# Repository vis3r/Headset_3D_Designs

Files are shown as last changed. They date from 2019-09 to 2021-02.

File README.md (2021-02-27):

# Headset_3D_Designs
## The Vis3r Open Source 3D printable headset - STL and STEP source files. 

At current prices, you ought to be able to print this and get all the electronic components that you need for less than €75, although this changes on a daily basis. The components are often on special offer on AliExpress & Banggood, so it really pays to shop around.

The Headset was designed by Justin, the CAD files for the MIPI and HDMI boards were kindly provided by **Bio Toa7**

## The headset has finished Beta Testing
Here we are in early 2021, just coming out of virus lockdown - which unfortunately stopped our project development for what seemed like forever. However, we have still managed to finish Beta testing the headset and have finally released it out into the wild. The entire design was done from scratch in Autodesk Fusion 360 using one of their free licenses. The original F360 files can be given to anyone who needs them, so just ask.

If you find a problem, please post an issue and we will do our best to fix it ASAP. 

## Basic printing instructions
The headset is made of three main components, some of which have multiple parts. The entire design is purpose made to print with no supports. You shouldn't need to use a Skirt either, although a small Brim is probably a good idea.

### The Visual_Guide, Screen_Holder and Lens_Slides
As these incorporate screw threads and sliding components, you need to print with these settings:

* NO SUPPORTS
* 95% Infill
* 2 perimiter walls
* 4 Top Layers, 4 bottom layers

There are actually almost no "thick" areas, so they are very lightweight. A layer height of 0.2 or 0.24 is fine for these.

### The Main Body
As long as you print this with 2 perimiter walls, you can drop the infill down to 5% - & you will still find that they are rock solid. Again, they are designed specifically to print with NO SUPPORTS. Because they are almost completely hidden by the Outer_Shell, you can easily print these with a layer height of  0.24 or 0.28, and I would definitely not advise any lower than 0.2

* NO SUPPORTS
* 5% Infill
* 2 perimiter walls
* 4 Top Layers, 4 bottom layers

### The Outer Shell
The Outer Shell is basically a twin wall shell with a four layer lip at the bottom. As it has nothing that could ever be described as "thick", you can print it with these settings:

* NO SUPPORTS
* 95% Infill
* 2 perimiter walls
* 4 Top Layers, 4 bottom layers

Again, a layer height of 0.2 works beautifully for this, although even with 0.24 and 0.28 it's hard to tell the difference. 

### The Fasteners
The Main Body is clipped together with eight round pegs and two triangular bars. These are not load bearing and as such can also very happily be printed with our 5% infill, twin perimiter wall and four top/bottom layers.

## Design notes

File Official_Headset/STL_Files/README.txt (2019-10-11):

This headset has been specifically designed to print with ABSOLUTELY NO SUPPORT

It has also been designed for most of the parts to be printed with only 5% infill, 2 perimiter walls and four top or bottom layers.

Check the README.txt in each folder for specific details.

THIS IS IMPORTANT
+++++++++++++++++
Cura will default to using a "Wall Line Count" of THREE. There is a huge difference between using a "Wall Line Count" of THREE and a "Wall Line Count" of TWO.

Both the Left_Hand_Frame and the Right_Hand_Frame will take 20% longer to print and will weigh 25% more - but will gain you nothing. Honestly, they won't be any stronger, they'll just weigh more. For the record, you can't drop it down to a "Wall Line Count" of ONE - it just doesn't work.

For the MAIN_BODY, it is really not neccessary to print the Left_Hand_Frame and Right_Hand_Frame at a low layer height. They will be hidden behind the Outer_Shell, and as such, can be printed ant 0.24 or 0.28 Layer Heights with no noticable adverse visual effects.

The FrontPlate is best printed at a Layer Height of 0.16 or 0.20, although it still looks fine at 0.28 too.

You will need to work out your Inter-Pupillary Distance (centre of eyeball to centre-line of nose). This involves printing the IPD_Ruler PDF file in this folder and taking a selfie. Alternatively, you can ask a friendly optician, but the selfie is probably quicker and easier.

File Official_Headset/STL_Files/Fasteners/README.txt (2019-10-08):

You will need to print:

 EIGHT FrontPlate-Mounts
 TWO Tribars
 ONE Headstrap-Clip-LHS
 ONE Headstrap-Clip-RHS

These are simple clips, not load supporting. Honestly, you only need these settings:

5% Infill (Yes, honestly, only 5%)
2 Side Walls
4 Top and Bottom layers

I have successfully printed these using Layer Heights of 0.16, 0.20, 0.24 and 0.28

Often, you will need a BRIM to print the EIGHT Round FrontPlate-Mounts, because there's not much surface to properly stick to the bed. I also tend to print a few extra, as they have a nasty habit of rolling off the desk & getting lost.

The two Tribars, Headstrap-Clip-LHS and Headstrap-Clip-RHS don't really need a BRIM to print, but naturally, YMMV.

SPAGHETTI ALERT
===============
The tribars load into Cura on a corner, rather than flat - but they "look" OK until you rotate the view. Watch out for this & rotate them so they are flat, or else you'll be finding more filament spaghetti than you really wanted.

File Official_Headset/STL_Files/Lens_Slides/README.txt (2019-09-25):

You will need to print TWO Lens-Screws and TWO Lens-Caps (as you need one of each for both Lens_Slides).
You only need ONE Left_Hand_Side and ONE Right_Hand_Side Lens_Slide

Because these are screw threads, you need to print them with the following settings:

95% Infill
2 Side Walls
4 Top and Bottom layers

I have successfully printed these using Layer Heights of 0.16, 0.20, 0.24 and 0.28

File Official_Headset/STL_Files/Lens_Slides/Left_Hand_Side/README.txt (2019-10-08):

You only need ONE of these! Measure your Inter-Pupillary Distance (IPD) & print the one that fits you.

Note: Most people are not symmetrical, so your Left and Right measurements will almost certainly be different.

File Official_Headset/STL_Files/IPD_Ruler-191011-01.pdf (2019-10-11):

50 | 40 | 30 | 20 | 10 | 0 | 10 | 20 | 30 | 40 | 50

Vis3r Inter-Pupillary Distance Ruler

Print it out, cut it out,tape it to your forehead, then take a selfie - or ask a friend to help you.

You need to measure the centre point of each pupil Open your selfie in any image package & draw a line, or even just move the edge of another window over it

The “0” needs to be exactly on the centre line of your nose don’t forget everything is mirrored in your selfie This example gives a Left IPD of 27 & a Right IPD of 28 Do your best to be as accurate as possible

Doc Ver: 191011-01

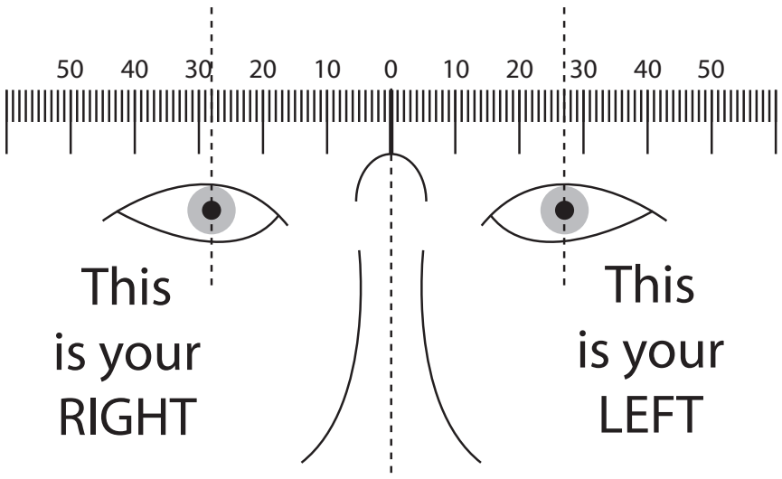
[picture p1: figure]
This is your RIGHT; This is your LEFT

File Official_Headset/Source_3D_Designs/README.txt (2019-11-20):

The Lens_Slide files are the full parametric versions of the slides. The version in the main file is far less easy to work with.

I hope to clean the main source file up as soon as I get a spare moment, as it has a year's worth of design iterations inside it. If you are a Fusion 360 genius, you could probably recreate the whole headset from scratch in a weekend, which would probably really neaten things up. If you want to, or need any other help with this, please PM me on our Discord.

Justin.

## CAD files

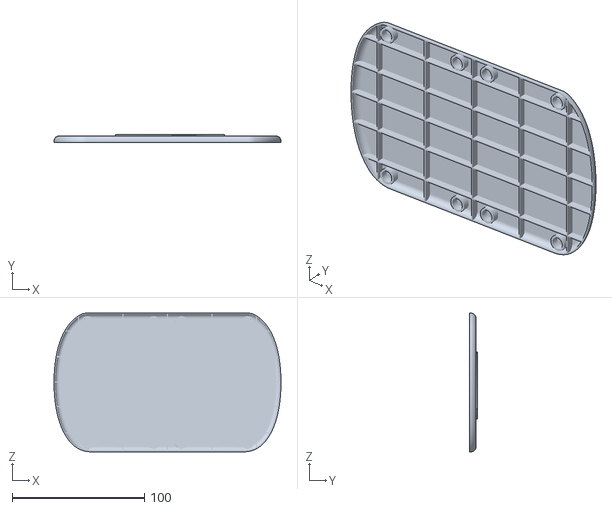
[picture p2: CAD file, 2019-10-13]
Official_Headset/STL_Files/Main_Body/FrontPlate-FULLSIZE_191013-01.stl
171.9 x 6.00 x 105.0

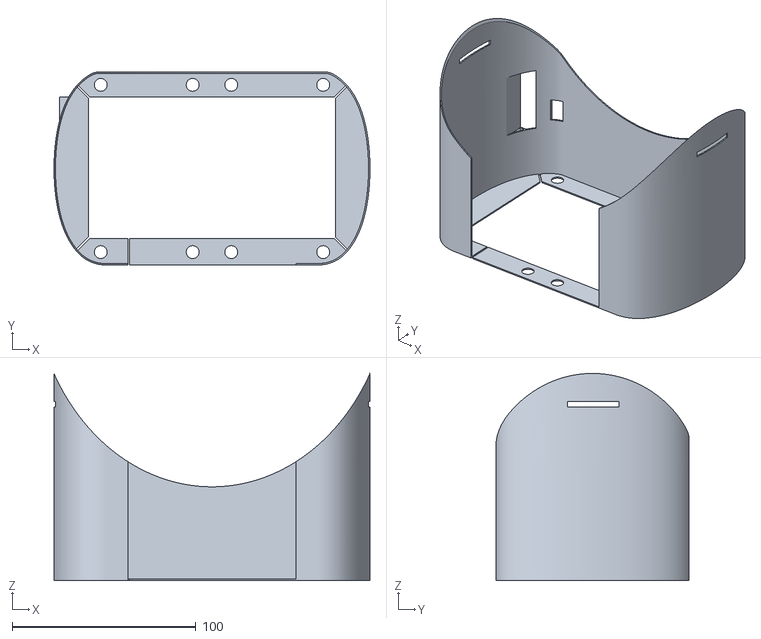
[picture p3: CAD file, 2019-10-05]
Official_Headset/STL_Files/Main_Body/Outer_Shell-FULLSIZE_191005-01.stl
171.9 x 105.0 x 112.7

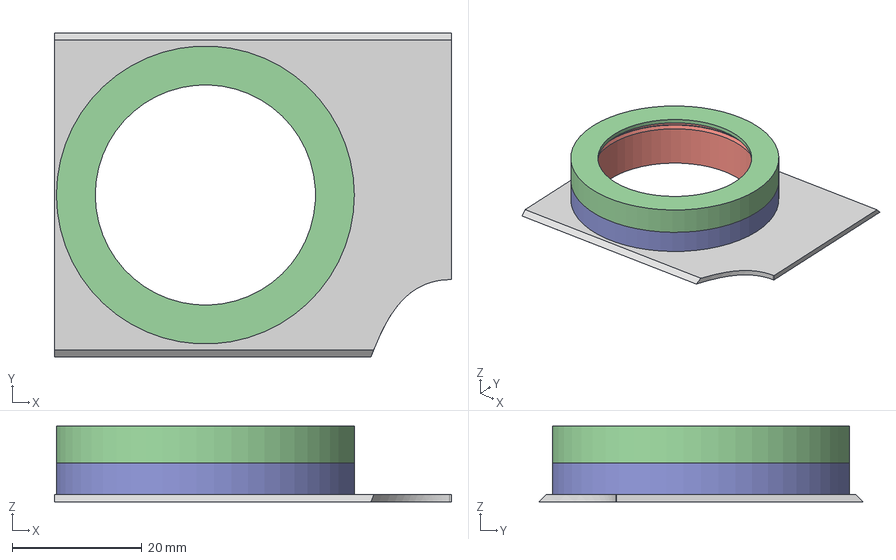
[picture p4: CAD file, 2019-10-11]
Official_Headset/Source_3D_Designs/Lens_Slide_LHS-191011-01.step
61.3 x 50.0 x 11.7 mm
Socket
Screw
Cap

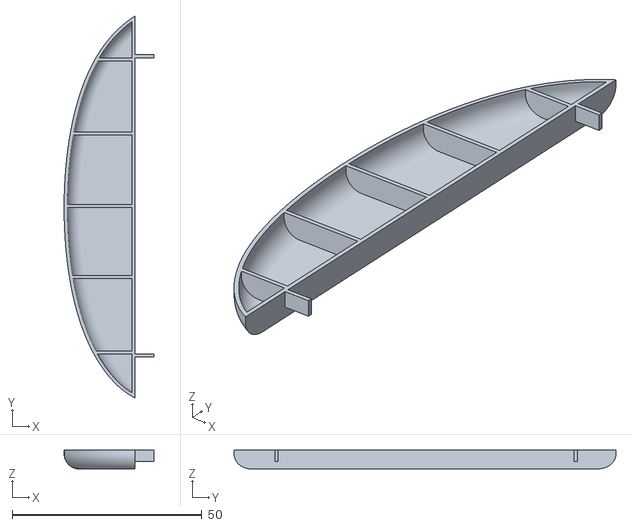
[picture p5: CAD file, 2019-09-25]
Official_Headset/STL_Files/Beta/15x15_Print_Bed/FrontPlate_15cm/BETA_FrontPlate-RHS-15cm_190924-01.stl
23.7 x 100.8 x 5.00

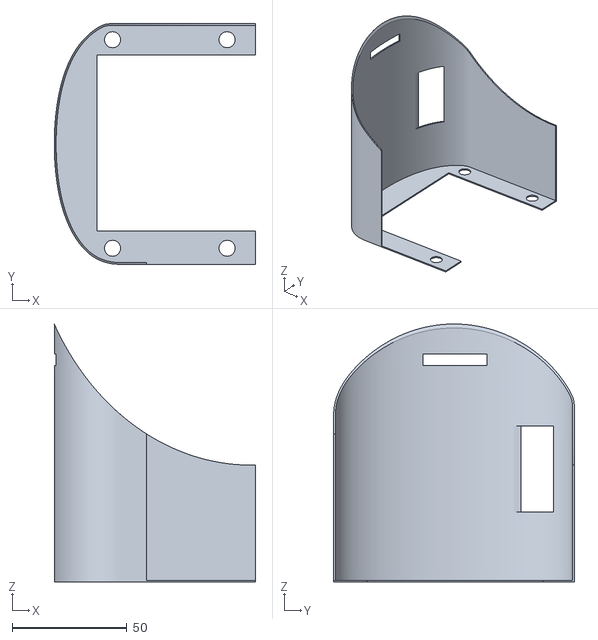
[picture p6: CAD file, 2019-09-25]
Official_Headset/STL_Files/Beta/15x15_Print_Bed/Outer_Shell_15cm/BETA_Outer-Shell-LHS-15cm_190924-01.stl
87.9 x 105.0 x 112.6

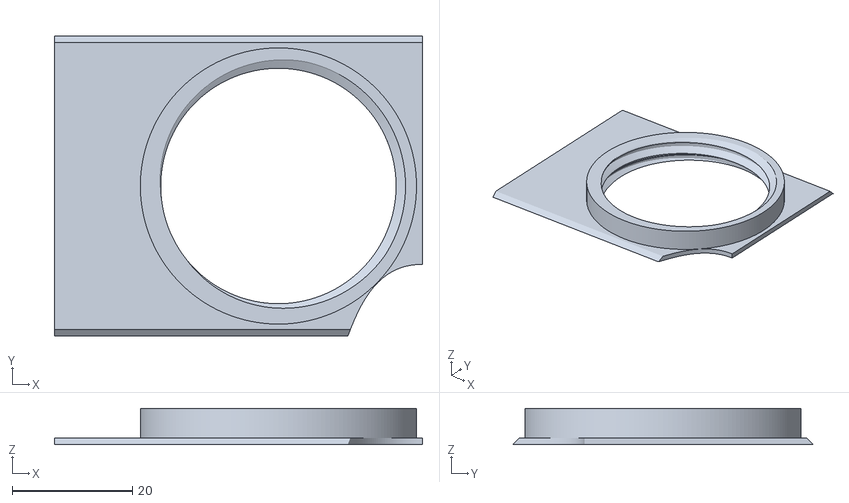
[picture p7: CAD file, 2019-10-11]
Official_Headset/STL_Files/Lens_Slides/Left_Hand_Side/Lens-Slide-LHS-24mm_191011-01.stl
61.3 x 50.0 x 6.00

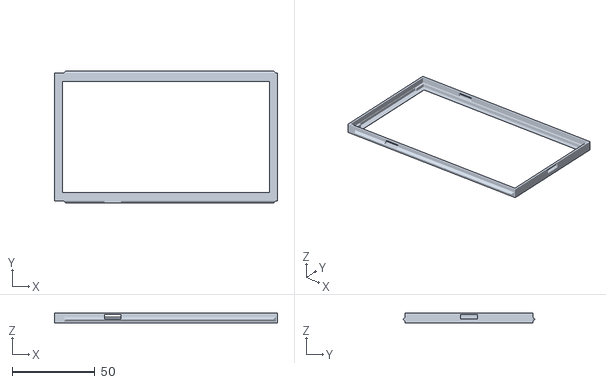
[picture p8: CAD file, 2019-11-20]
Official_Headset/STL_Files/Visual_Guide_&_Screen_Holder/Screen_Holder_+0.05mm-offset_191120-01.stl
134.4 x 79.7 x 6.00

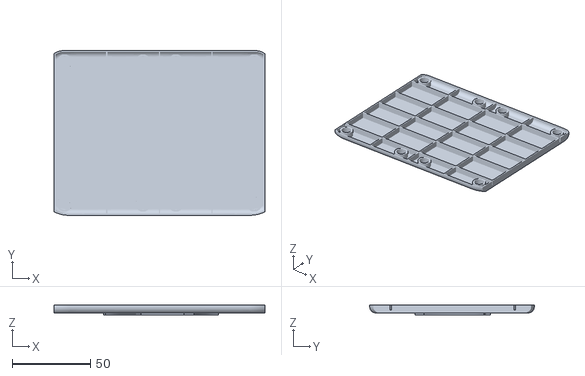
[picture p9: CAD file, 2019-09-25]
Official_Headset/STL_Files/Beta/15x15_Print_Bed/FrontPlate_15cm/BETA_FrontPlate-MIDDLE-15cm_190924-01.stl
134.5 x 105.0 x 6.20

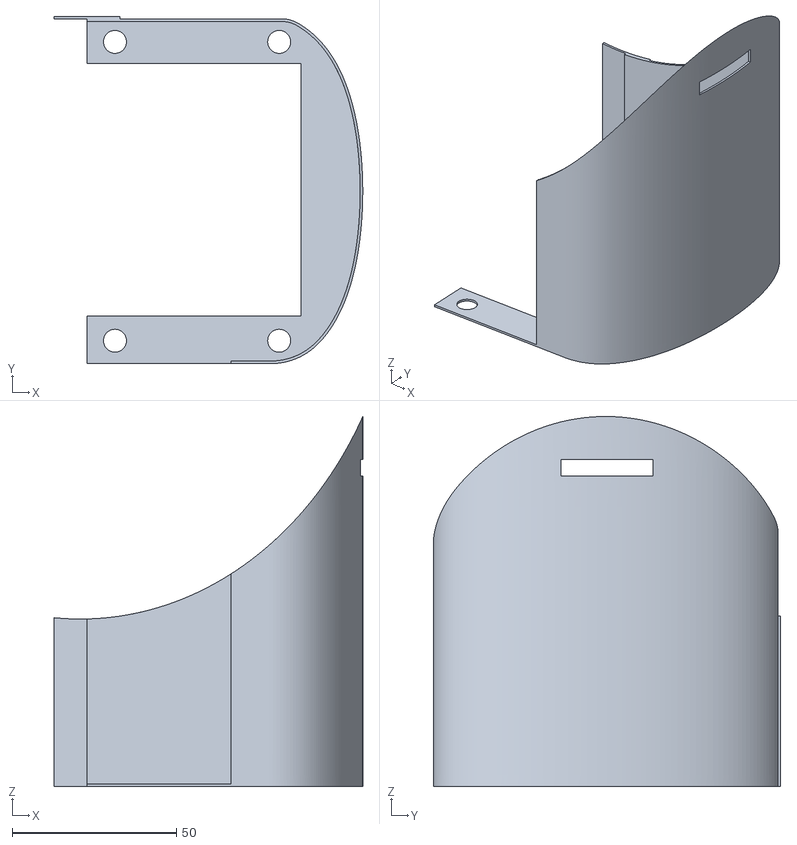
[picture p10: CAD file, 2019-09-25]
Official_Headset/STL_Files/Beta/15x15_Print_Bed/Outer_Shell_15cm/BETA_Outer-Shell-RHS-15cm_190924-01.stl
94.0 x 105.8 x 112.7

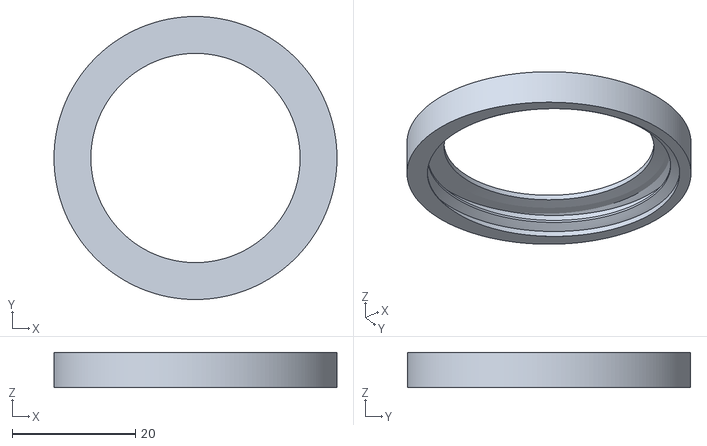
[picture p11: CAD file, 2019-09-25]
Official_Headset/STL_Files/Lens_Slides/Lens-Cap_190924-01.stl
46.0 x 46.0 x 5.70

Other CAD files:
Official_Headset/STL_Files/Main_Body/FrontPlate-FULLSIZE_191006-01.stl
Official_Headset/STL_Files/Lens_Slides/Right_Hand_Side/Lens-Slide-RHS-31mm_191011-01.stl
Official_Headset/Source_3D_Designs/Lens_Slide_RHS-191011-01.step
Official_Headset/STL_Files/Lens_Slides/Left_Hand_Side/Lens-Slide-LHS-26mm_191011-01.stl
Official_Headset/STL_Files/Lens_Slides/Right_Hand_Side/Lens-Slide-RHS-24mm_191011-01.stl
Official_Headset/STL_Files/Visual_Guide_&_Screen_Holder/Screen_Holder_+0.1mm-offset_191120-01.stl
Official_Headset/STL_Files/Beta/15x15_Print_Bed/FrontPlate_15cm/BETA_FrontPlate-LHS-15cm_190924-01.stl
Official_Headset/STL_Files/Lens_Slides/Left_Hand_Side/Lens-Slide-LHS-28mm_191011-01.stl
Official_Headset/STL_Files/Fasteners/FrontPlate-Mount_191006-03.stl
Official_Headset/STL_Files/Fasteners/Headstrap-Clip-LHS_190924-01.stl
Official_Headset/STL_Files/Fasteners/Headstrap-Clip-RHS_190924-01.stl
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

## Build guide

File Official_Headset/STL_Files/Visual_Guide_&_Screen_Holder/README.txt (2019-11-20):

You only need ONE Visual_Guide and ONE Screen_Holder

Because these are mostly twin wall items or sliding mechanisms, you need to print them with the following settings:

NO SUPPORTS
95% Infill
2 Side Walls
4 Top and Bottom layers

I have successfully printed these using Layer Heights of 0.16, 0.20, 0.24 and 0.28

If you are printing this with an absolutely perfectly flat bed with beautiful adhesion (ie glass), you can easily print both the Visual_Guide and Screen_Holder with only a small brim. However, if your bed is not 100% perfect (such as my Ender 3 Magnetic Build Plate) you may need a 5 to 10mm skirt to stop it lifting at the corners.

Because these parts hold the screen, you really do need to get them decently printed. If your print starts to lift at the corners you will need to redo it. I had to use Isopropyl Alcohol to clean my Ender Magnetic Bed and print it with a 10mm skirt - after which it stuck perfectly and printed well. However, on my mirror glass bed with Blue Tape wiped down with Acetone, it stuck beautifully with no skirt required & only a small brim 1cm away from the print. Basically, every printer is different, so do what you have to do to get it to stick properly.

IMPORTANT
There are now THREE versions of the Screen_Holder stl files. Because people's printers are different, sometimes the tolerances just don't work. This is normally fine, & you can force things together - except that the screens we use are _really_ fragile, and if you don't take care, it will break & you will need to replace it. 

Screen_Holder_DATE_VERSION.stl
Screen_Holder_+0.05mm-offset_DATE_VERSION.stl
Screen_Holder_+0.1mm-offset_DATE_VERSION.stl

Please, do not make the mistake of trying to "force" your screen in. Honestly, you will break it. Because the Screen_Holder is a quick part to print, and doesn't use much filament, I would advise starting out with the +0.1mm-offset version, & if you feel that your screen is too loose, try the +0.05mm version & then the default version. It is far easier to do another 45 minute print using 3m of filament than to replace a cracked screen...

The default version has a gap of 0.25mm on each edge around the screen. The +0.05mm version gives a gap of 0.3mm and the +0.1mm-offset version gives a gap of 0.35. Just remember that these offsets are added to both sides of the screen.

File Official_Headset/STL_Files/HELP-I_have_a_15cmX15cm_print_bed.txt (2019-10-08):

HELP-I have a 15cmX15cm print bed

No Problem...!

Most of the headset actually fits on a 15x15cm print bed.

However, there are special versions of the Outer_Shell and FrontPlate designed for a smaller print bed

Just look for the 15x15_Print_Bed folder

You will have to glue some of the bits together, but it's the best we could do for you.

Sorry, this is still in BETA for now - but it should be fully ready in a couple of days...

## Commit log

2019-09-25 STL Files Upload
    Added the current batch of STL files
    [BETA_FrontPlate-FULLSIZE_190924-01.stl, BETA_FrontPlate-LHS-15cm_190924-01.stl, BETA_FrontPlate-MIDDLE-15cm_190924-01.stl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]
2019-09-26 Update README.txt
    updated printing hints
2019-09-27 Fixed stringing overhangs
    I fixed the overhangs just above the bottom zigzags (which hold the Screen_Holder) which I had somehow missed when I was chanfering everything.
    [BETA_Left_Hand_Frame_190927-01.stl, BETA_Right_Hand_Frame_190927-01.stl]
2019-09-27 Tribar offset
    increased Tribar offset to reduce filing
    [BETA_Left_Hand_Frame_190927-02.stl, BETA_Right_Hand_Frame_190927-02.stl]
2019-09-29 Fix sensor orientation
    I had to rotate the sensor mount as I had mixed something up and was somehow 90° out - & that meant that I needed more space. It should work perfectly for the BNO055 breakout board now though. Plus I fixed lots of README files
    [BETA_Left_Hand_Frame_190924-01.stl, BETA_Left_Hand_Frame_190927-01.stl, BETA_Left_Hand_Frame_190927-02.stl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]
2019-10-02 Added USB Splitter
    When I was designing the headset, I forgot to add the USB Splitter cable - or at least a mount for it. It should now slot in nicely. I also tweaked the tolerances on the Tribar holes again so that you won't need to sand down the tribars to get everything to fit.
    [BETA_Left_Hand_Frame_190929-01.stl, BETA_Left_Hand_Frame_191002-01.stl, BETA_Outer_Shell-FULLSIZE_190924-01.stl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]
2019-10-03 Create BETA_Outer_Shell-FULLSIZE_191003-01.stl
    Added some slots to allow the outer shell to bend as you are clipping it in place - otherwise, if you get to heavy handed you could break it
    [BETA_Outer_Shell-FULLSIZE_191003-01.stl]
2019-10-04 Final cosmetic updates
    Fixed the logo for printing nicely, added a guard to the HDMI port, extended the FrontPlate Mounts by a bit so they stick better. I think this is the last of the BETA Testing changes. Hopefully.
    [BETA_FrontPlate-FULLSIZE_190924-01.stl, BETA_FrontPlate-FULLSIZE_191004-01.stl, BETA_FrontPlate-Mount_191004-01.stl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]
2019-10-05 Bridge Support
    I added a hard coded support for an over enthusiastically long bridge, which was giving some people huge problems on the Left_Hand_Frame. Plus, I fixed an overhang on the Outer Shell on the HDMI guard.
    [BETA_Left_Hand_Frame_191002-01.stl, BETA_Left_Hand_Frame_191005-01.stl, BETA_Outer_Shell-FULLSIZE_191004-01.stl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]
2019-10-08 End of BETA Testing
    The headset is now officially ready :-)
    The 15x15cm Print Bed version is still in Beta as I need to update some of it's dsigns a bit, but the normal headset is ready for the real world.
    [BETA_FrontPlate-FULLSIZE_191004-01.stl, BETA_FrontPlate-Mount_190924-01.stl, BETA_FrontPlate-Mount_191004-01.stl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]
2019-10-11 Lens_Slide variants and more source files
    I completely forgot to upload all of the different Lens_Slide variations for each individual IPD measurement. These are now live. I have also updated the Fusion 360 F3D and STEP files in the source f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
    [Lens-Slide-LHS-24mm_191011-01.stl, Lens-Slide-LHS-25mm_191011-01.stl, Lens-Slide-LHS-26mm_191011-01.stl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]
2019-10-13 Create FrontPlate-FULLSIZE_191013-01.stl
    fixed the Vis3r Logo
    [FrontPlate-FULLSIZE_191013-01.stl]
2019-11-20 Screen_Holder Offsets updated
    Extra versions of the Screen_Holder hae been added with an increased "gap" between the holdr and the edge of the physical screen, as it was reported that it was too tight and risked breaking the screen.
    [Screen_Holder_+0.05mm-offset_191120-01.stl, Screen_Holder_+0.1mm-offset_191120-01.stl]
2021-02-27 Update README.md
    Added accreditation for Bio Toa7 on the MIPI and HDMI boards
